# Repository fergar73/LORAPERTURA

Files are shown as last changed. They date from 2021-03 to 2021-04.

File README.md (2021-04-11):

## LORAPERTURA
El dispositivo lorapertura permite saber cuando una puerta está abierta o cerrada e informar de su estado a traves de la red Lorawan abierta y global [The Things Network](https://www.thethingsnetwork.org). Ofrece información de temperatura, presión y humedad del sitio donde esté instalado así como la luminosidad del espacio.
En la [presentación del proyecto](./presentacion/lorapertura-ttnmad.pdf) puedes consultar algunos detalles adicionales. 
- [English README file](README-EN.md)

### Hardware
Listado de componentes necesarios para la construcción del dispositivo
- Nodo TTN Madrid: Consulta esta  [documentación]( https://github.com/IoTopenTech/Nodo_TTN_MAD_V2) y sigue los pasos de esta [guía](https://github.com/IoTopenTech/Nodo_TTN_MAD_V2/blob/master/Montaje%20nodo%20TTN%20MAD%20v2_2%20basico.pdf) para construirlo.
- Sensor magnético puerta abierta
- Sensor Bosch BME280
- Sensor TEMT6000 

En la presentacion se indica la forma elegida de conectar los sensores al nodo TTN Madrid.

### Software
Se proporcionan dos programas ".ino" de arduino en el directorio del software dependiendo de la forma preferida (OTAA O ABP) de conectar el dispositivo a [The Things Network](https://www.thethingsnetwork.org).

Se ha utilizado el Arduino IDE para este proyecto, los detalles se indican en [SW-Arduino-IDE](software/SW-Arduino-IDE.md)

### 3D - Caja Dispositivo 
Se propone una caja de interior junto con su tapa para fijar el dispositivo a la pared en la carpeta caja-3d. Este dispositivo se ha realizado utilizando [freecad](https://www.freecadweb.org)
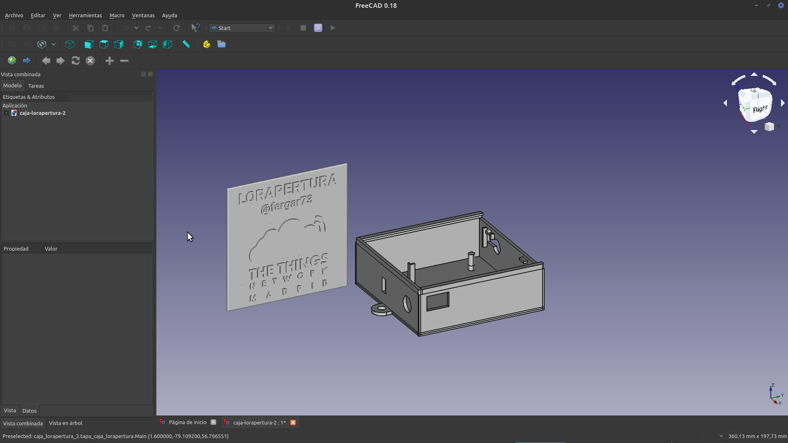
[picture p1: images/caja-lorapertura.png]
caja-lorapertura


### Visualización de Datos
La capa de presentación y control del dispositivo lorapertura se ha realizado utilizando [myiotopentech](https://my.iotopentech.io/) que está básado en la plataforma de código abierto [thingsboard](https://thingsboard.io/) que permite gestionar la recolección de datos de dispositivos de IoT, su procesamiento y visualización. 
Aquí está [la información detallada de myiotopentech]( https://github.com/IoTopenTech/myIoTopenTech). El nombre interno del dispositivo lorapetura es TTNMAD-DOOR-BME280-TEMT6000 y a continuación se muestra el panel principal que muestra los datos de lorapertura
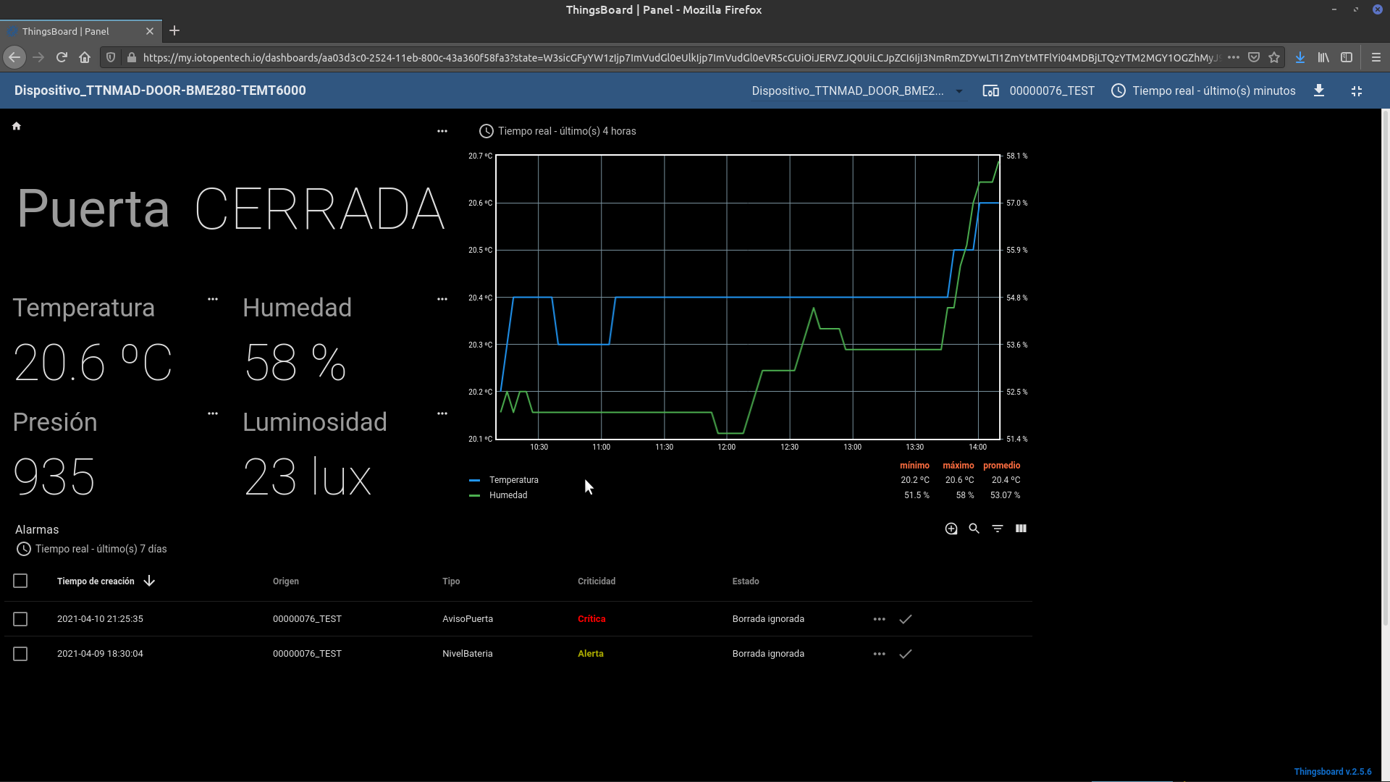
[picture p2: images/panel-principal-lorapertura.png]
panel principal


### Contribuciones
Se pueden realizar contribuciones al proyecto, puedes hacer un fork en local y plantear los pull-request con las mejoras realizadas.

### Licencia
LORAPERTURA © 2021 por fergar73 esta bajo licencia CC BY-NC-SA [Creative Commons Reconocimiento-NoComercial-CompartirIgual 4.0 Internacional License](http://creativecommons.org/licenses/by-nc-sa/4.0/)
 
### Agradecimientos
Este proyecto ha sido posible gracias a la extraordinaria labor que se está realizando la comunidad [The Things Network Madrid](https://www.thethingsnetwork.org/community/madrid/)

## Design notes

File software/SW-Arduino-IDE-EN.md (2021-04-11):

## Build on Arduino IDE
You can install the Arduino IDE by downloading it from [arduino.cc](https://www.arduino.cc). This project has been developed using 1.8.13 release. 

### Installing dependencies
This project relies on several third party dependencies that must be installed in order to be able to build the binary. Below the list of libraries used:

- <lmic.h>             // For the Lorawan comunication - Release v2.3.2
https://github.com/mcci-catena/arduino-lmic
- <LowPower.h>         // To allow the low power arduino energy  consumption Release v1.6.0
https://github.com/rocketscream/Low-Power
- <forcedClimate.h>    // Getting BME280 data Release v3.0.0
https://github.com/JVKran/Forced-BME280
- <YetAnotherPcInt.h>  // To choose the port for the door control interruption Release v2.1.0
https://github.com/paulo-raca/YetAnotherArduinoPcIntLibrary 
- <CayenneLPP.h>       // Cayenne Library for the payload format Release v1.0.1
https://github.com/ElectronicCats/CayenneLPP

Once you have installed and downloaded the repository in the software directory, the code is available to compile it and upload it to the lorapertura device.
Remember that you must fill in the specific data of your device in FILLMEIN depending on the configuration (OTAA or ABP) of your device in [The Things Network](https://www.thethingsnetwork.org) 

Code to replace FILLMEIN in ABP device
```c
// LoRaWAN NwkSKey, network session key
static const PROGMEM u1_t NWKSKEY[16] = { FILLMEIN } ;`

// LoRaWAN AppSKey, application session key
static const u1_t PROGMEM APPSKEY[16] = { FILLMEIN } ;

// LoRaWAN end-device address (DevAddr)
// See http://thethingsnetwork.org/wiki/AddressSpace
// The library converts the address to network byte order as needed.
static const u4_t DEVADDR = FILLMEIN ; // <-- Change this address for every node!
```

### Select board and upload the binary 
Two options selecting the board depending on the bootloader of the ttnmad node:
If you load the Minicore bootloader as indicated in the doc as optional then select ATmega328 board
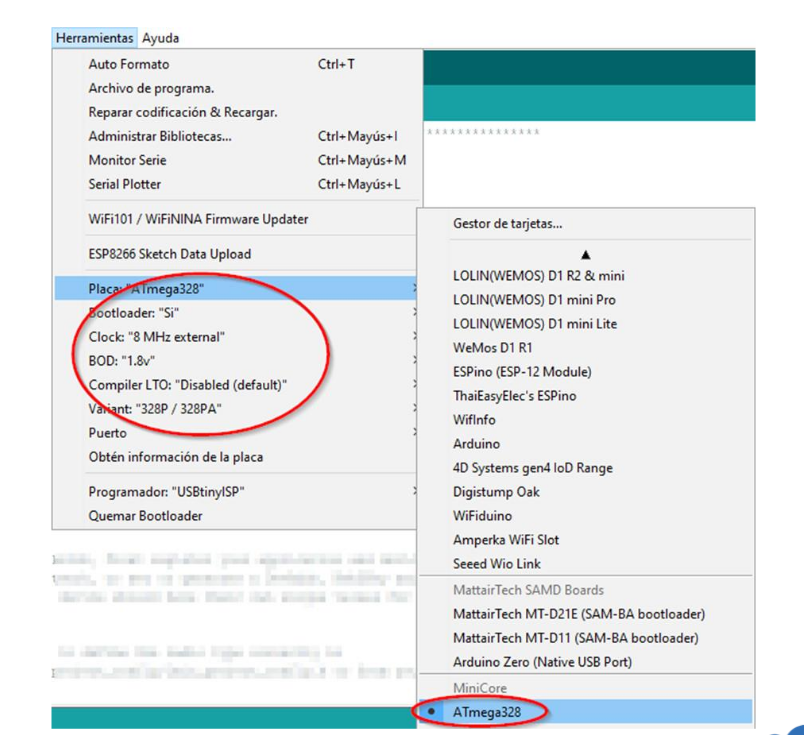
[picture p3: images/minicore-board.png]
minicore

otherwise you have to choose the "Arduino Pro or Pro Mini" board.
arduino-mini
Then select the port where the board is connected to the computer in Tools > Ports
And finally click on the rounded arrow button on the top to upload the project to the board or go to Program > Upload (Ctl+U)

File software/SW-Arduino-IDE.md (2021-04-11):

## Programación con Arduino IDE
Puedes instalar el arduino IDE disponible en [arduino.cc](https://www.arduino.cc). Este proyecto ha sido desarrollado con la versión 1.8.13.

### Dependencias
Este proyecto requiere de la instalación en el arduino IDE de las siguientes librerías. Son necesarias para la compilación y correcto funcionamiento del dispositivo. 

- <lmic.h>             // For the Lorawan comunication - Release v2.3.2
https://github.com/mcci-catena/arduino-lmic
- <LowPower.h>         // To allow the low power arduino energy  consumption Release v1.6.0
https://github.com/rocketscream/Low-Power
- <forcedClimate.h>    // Getting BME280 data Release v3.0.0
https://github.com/JVKran/Forced-BME280
- <YetAnotherPcInt.h>  // To choose the port for the door control interruption Release v2.1.0
https://github.com/paulo-raca/YetAnotherArduinoPcIntLibrary 
- <CayenneLPP.h>       // Cayenne Library for the payload format Release v1.0.1
https://github.com/ElectronicCats/CayenneLPP

Una vez tengas instalado y descargado el repositorio en el directorio software está el código disponible para compilarlo y subirlo al dispositivo lorapertura.
Recuerda que debes rellenar los datos concreto de tu dispositivo en FILLMEIN dependiendo de la configuración (OTAA o ABP) de tu dispositivo en [The Things Network](https://www.thethingsnetwork.org)

Lugar del código activación ABP donde sustituir el FILLMEIN 
```c
// LoRaWAN NwkSKey, network session key
static const PROGMEM u1_t NWKSKEY[16] = { FILLMEIN } ;`

// LoRaWAN AppSKey, application session key
static const u1_t PROGMEM APPSKEY[16] = { FILLMEIN } ;

// LoRaWAN end-device address (DevAddr)
// See http://thethingsnetwork.org/wiki/AddressSpace
// The library converts the address to network byte order as needed.
static const u4_t DEVADDR = FILLMEIN ; // <-- Change this address for every node!
```

### Selección de la placa y carga del programa en el dispositivo

Hay 2 opciones de seleccionar la placa dependiendo del "bootloader" que tenga cargado el nodo TTNMAD.
Si tiene cargado el Minicore bootloader que se indica en la documentación como paso opcional, hay que indicar la placa ATmega328 
minicore
si no es el caso hay que seleccionar la placa "Arduino Pro or Pro Mini" con procesador ATmega328P (3.3V,8MHz).
arduino-mini
Seleciona el puerto que esté conectado a la placa y mediante el arduino IDE pulsa la opción de subir el código (Ctl+U)

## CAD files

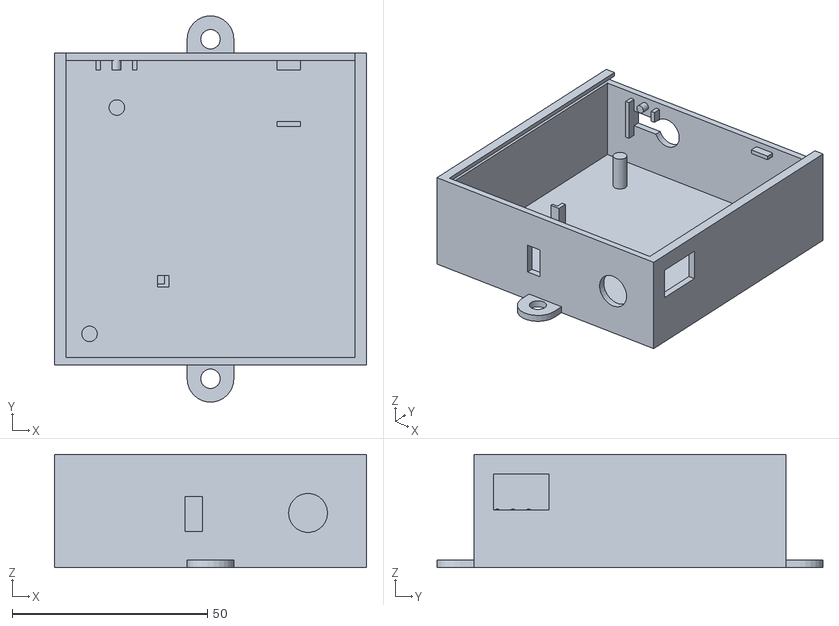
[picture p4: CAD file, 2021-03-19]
caja-3d/caja-lorapertura.stl
80.0 x 98.9 x 29.0

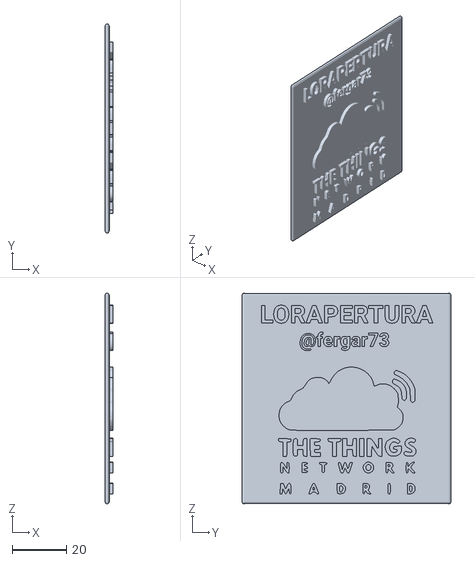
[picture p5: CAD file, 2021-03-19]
caja-3d/tapa-caja-lorapertura.stl
3.00 x 76.9 x 77.6

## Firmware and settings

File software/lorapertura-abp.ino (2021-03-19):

/*******************************************************************************
 * Copyright (c) 2015 Thomas Telkamp and Matthijs Kooijman
 * Copyright (c) 2018 Terry Moore, MCCI
 * Copyright (c) 2020 Fernando García Martín
 *
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
 *
 * This uses ABP (Activation-by-personalisation), where a DevAddr and
 * Session keys are preconfigured (unlike OTAA, where a DevEUI and
 * application key is configured, while the DevAddr and session keys are
 * assigned/generated in the over-the-air-activation procedure).
 *
 * Note: LoRaWAN per sub-band duty-cycle limitation is enforced (1% in
 * g1, 0.1% in g2), but not the TTN fair usage policy (which is probably
 * violated by this sketch when left running for longer)!
 *
 * To use this sketch, first register your application and device with
 * the things network, to set or generate a DevAddr, NwkSKey and
 * AppSKey. Each device should have their own unique values for these
 * fields.
 *
 * Do not forget to define the radio type correctly in
 * arduino-lmic/project_config/lmic_project_config.h or from your BOARDS.txt.
 *
 *******************************************************************************/

 // References:
 // [feather] adafruit-feather-m0-radio-with-lora-module.pdf

#include <lmic.h>             // Libreria para la implementación del protocolo Lorawan
#include <hal/hal.h>          // Hardware Abstraction Layer for LMIC
#include <SPI.h>              // Bus SPI - utilizado para la comunicación con el RFM95
#include <Wire.h>             // Bus I2C - utilizado para comunicación con el BME280
#include "LowPower.h"         // Librería para la gestión de bajo consumo del arduino
#include <forcedClimate.h>    // Librería para acceder al sensor BME280 con bajo consumo de memoria
#include <YetAnotherPcInt.h>  // Permite elegir el puerto para la gestión de la interrupción de puerta abierta.
#include <CayenneLPP.h>       // Construcción del payload en formato Cayenne

// Define el SpreadFactor fijo que se utilizará en la transmisión Lora
#define SpreadFactor DR_SF7
// Indicar el tiempo que tarda el mensaje en el aire según el Spread Factor indicado
// se puede utilizar para ello la utilidad: https://avbentem.github.io/airtime-calculator/ttn
const unsigned long airTimeMs = 61.7;  // Expresado en milisegundos

unsigned int frecuenciaEnvioMsg;  // Tiempo en segundos entre cada envio de mensaje, calculado en función del airTimeMs 
unsigned int tiempoDormido = 0;   // Control del tiempo que el procesador esta en modo LowPower

boolean modoAhorroEnergia = true; // Para activar o desactivar el modo LowPower  

// Definición de Pin A2 para Interrupción Sensor Puerta Abierta
#define pinEventoPuertaAbierta A2

// Variables para el control de la interrupción de Puerta Abierta 
volatile boolean eventoPuertaAbierta = false;   // Cuando se abre la puerta salta la interrupción y estará a true. Inicializada a false
boolean ev_antes_envio = false;                 // Contiene el valor de la variable eventoPuertaAbierta antes del envío.
boolean ev_despues_envio = false;               // Contiene el valor de la variable eventoPuertaAbierta despues del envío.

// Sensor de luminosidad - TEMT6000  
#define LIGHTSENSORPIN A0     //Conectado al pin Analogico A0 light sensor reading 
float lux = 0.0;              // Variable para enviar la luminosidad en lux

// Sensor BME280 conectado al puerto I2C en la dirección 0x76 para obtener datos de temperatura, presión y humedad
ForcedClimate climateSensor = ForcedClimate();

// Variable en formato Cayenne para el envío del payload a TTN. Se indica tamaño de cada campo del payload.
// LPP_ANALOG_INPUT_SIZE 4        -- 2 bytes  -- "analog_in_1"
// LPP_DIGITAL_OUTPUT_SIZE 3      -- 1 byte   -- "digital_out_2" y "digital_out_3"
// LPP_TEMPERATURE_SIZE 4         -- 2 bytes  -- "temperature_4"
// LPP_BAROMETRIC_PRESSURE_SIZE 4 -- 2 bytes  -- "barometric_pressure_5"
// LPP_RELATIVE_HUMIDITY_SIZE 3   -- 1 byte   -- "relative_humidity_6"
// LPP_LUMINOSITY_SIZE 4          -- 2 bytes  -- "luminosity_7"
CayenneLPP lpp(25);

// For normal use, we require that you edit the sketch to replace FILLMEIN
// with values assigned by the TTN console. However, for regression tests,
// we want to be able to compile these scripts. The regression tests define
// COMPILE_REGRESSION_TEST, and in that case we define FILLMEIN to a non-
// working but innocuous value.
//
#ifdef COMPILE_REGRESSION_TEST
# define FILLMEIN 0
#else
# warning "You must replace the values marked FILLMEIN with real values from the TTN control panel!"
# define FILLMEIN (#dont edit this, edit the lines that use FILLMEIN)
#endif

// LoRaWAN NwkSKey, network session key
static const PROGMEM u1_t NWKSKEY[16] = { FILLMEIN } ;

// LoRaWAN AppSKey, application session key
static const u1_t PROGMEM APPSKEY[16] = { FILLMEIN } ;

// LoRaWAN end-device address (DevAddr)
// See http://thethingsnetwork.org/wiki/AddressSpace
// The library converts the address to network byte order as needed.
static const u4_t DEVADDR = FILLMEIN ; // <-- Change this address for every node!

// These callbacks are only used in over-the-air activation, so they are
// left empty here (we cannot leave them out completely unless
// DISABLE_JOIN is set in arduino-lmic/project_config/lmic_project_config.h,
// otherwise the linker will complain).
void os_getArtEui (u1_t* buf) { }
void os_getDevEui (u1_t* buf) { }
void os_getDevKey (u1_t* buf) { }

static osjob_t sendjob;

// Pin mapping
// Adapted for Feather M0 per p.10 of [feather]
const lmic_pinmap lmic_pins = {
    .nss = 10,                       // chip select on feather (rf95module) CS
    .rxtx = LMIC_UNUSED_PIN,
    .rst = 9,                       // reset pin
    .dio = {2, 7, LMIC_UNUSED_PIN}, // assumes external jumpers [feather_lora_jumper]
                                    // DIO1 is on JP1-1: is io1 - we connect to GPO6
                                    // DIO1 is on JP5-3: is D2 - we connect to GPO5
};

int contador = 0;
boolean completado = false;

unsigned long inicio;   // Para controlar los tiempos de espera sin utilizar función delay.
unsigned long actual;   // Para controlar los tiempos de espera sin utilizar función delay.
unsigned long fin;      // Para controlar los tiempos de espera sin utilizar función delay.


// Funcion que devuelve el voltaje de las baterías
// Fuente Juan Félix Mateos - Talleres nodo v2.2 TTN MAD

long readVcc() {
  ADMUX = _BV(REFS0) | _BV(MUX3) | _BV(MUX2) |
  _BV(MUX1);
  delay(2);
  ADCSRA |= _BV(ADSC);
  while (bit_is_set(ADCSRA, ADSC));
  long result = ADCL;
  result |= ADCH << 8;
  result = 1126400L / result; // Back-calculate AVcc in mV
  return result;
}

void onEvent (ev_t ev) {
    Serial.print(os_getTime());
    Serial.print(": ");
    switch(ev) {
        case EV_SCAN_TIMEOUT:
            Serial.println(F("EV_SCAN_TIMEOUT"));
            break;
        case EV_BEACON_FOUND:
            Serial.println(F("EV_BEACON_FOUND"));
            break;
        case EV_BEACON_MISSED:
            Serial.println(F("EV_BEACON_MISSED"));
            break;
        case EV_BEACON_TRACKED:
            Serial.println(F("EV_BEACON_TRACKED"));
            break;
        case EV_JOINING:
            Serial.println(F("EV_JOINING"));
            break;
        case EV_JOINED:
            Serial.println(F("EV_JOINED"));
            break;
        /*
        || This event is defined but not used in the code. No
        || point in wasting codespace on it.
        ||
        || case EV_RFU1:
        ||     Serial.println(F("EV_RFU1"));
        ||     break;
        */
        case EV_JOIN_FAILED:
            Serial.println(F("EV_JOIN_FAILED"));
            break;
        case EV_REJOIN_FAILED:
            Serial.println(F("EV_REJOIN_FAILED"));
            break;
        case EV_TXCOMPLETE:
            if (LMIC.txrxFlags & TXRX_ACK)
              Serial.println(F("Received ack"));
            if (LMIC.dataLen) {
              Serial.println(F("Received "));
              Serial.println(LMIC.dataLen);
              Serial.println(F(" bytes of payload"));
            }
            // Variable completado se marca a cierto cuando se ha completado la transacción de envío.
            // Nos sirve para dar paso al próximo ciclo de envío con la seguridad que la transacción que estaba siendo gestionada ha terminado.
            completado = true;  
            Serial.println(F("EV_TXCOMPLETE (includes waiting for RX windows)"));
            break;
        case EV_LOST_TSYNC:
            Serial.println(F("EV_LOST_TSYNC"));
            break;
        case EV_RESET:
            Serial.println(F("EV_RESET"));
            break;
        case EV_RXCOMPLETE:
            // data received in ping slot
            Serial.println(F("EV_RXCOMPLETE"));
            break;
        case EV_LINK_DEAD:
            Serial.println(F("EV_LINK_DEAD"));
            break;
        case EV_LINK_ALIVE:
            Serial.println(F("EV_LINK_ALIVE"));
            break;
        /*
        || This event is defined but not used in the code. No
        || point in wasting codespace on it.
        ||
        || case EV_SCAN_FOUND:
        ||    Serial.println(F("EV_SCAN_FOUND"));
        ||    break;
        */
        case EV_TXSTART:
            Serial.println(F("EV_TXSTART"));
            break;
        default:
            Serial.print(F("Unknown event: "));
            Serial.println((unsigned) ev);
            break;
    }
}

void do_send(osjob_t* j){

    // Check if there is not a current TX/RX job running
    if (LMIC.opmode & OP_TXRXPEND) {
        Serial.println(F("OP_TXRXPEND, not sending"));
    } else {
    // Prepare upstream data transmission at the next possible time.
        lpp.reset();
        lpp.addAnalogInput(1, readVcc() / 1000.F);                        // Enviamos Voltaje actual 
        climateSensor.takeForcedMeasurement();                            // Obtenemos los datos de temperatura, presión y humedad del BME280
        lpp.addTemperature(4, climateSensor.getTemperatureCelcius());     // Enviamos la medición de temperatura
        lpp.addBarometricPressure(5, climateSensor.getPressure());        // Enviamos la medición de presión
        lpp.addRelativeHumidity(6, climateSensor.getRelativeHumidity());  // Enviamos la medición de humedad
        lux = ((((analogRead(LIGHTSENSORPIN) * 3.3 / 1024) / 10000.0) * 1000000) * 2.0 );  // Obtenemos la medición de luminosidad de TEMT6000 y la pasamos a lux
        lpp.addLuminosity(7,lux);                                         // Enviamos la medición de luminosidad        
        ev_antes_envio = eventoPuertaAbierta;                             // Guardamos el valor del eventoPuertaAbierta antes del envío
        lpp.addDigitalOutput(2, eventoPuertaAbierta);                     // Enviamos valor de eventoPuertaAbierta para saber si ha saltado la interrupción de Puerta Abierta
        lpp.addDigitalOutput(3, digitalRead(pinEventoPuertaAbierta));     // Estado de la puerta 1 => Cerrada || 0 => Abierta
        LMIC.pendTxConf = eventoPuertaAbierta;                            // Si se ha producido el evento de puerta abierta activamos el envío del mensaje con ACK
        LMIC_setTxData2(1, lpp.getBuffer(), lpp.getSize(), LMIC.pendTxConf);  //  Se hace el envío del mensaje a TTN
        ev_despues_envio = eventoPuertaAbierta;                           // Guardamos el valor del eventoPuertaAbierta despues del envío
        Serial.print(F("Paquete enviado a TTN "));
        Serial.print("ev_antes_envio ");Serial.print(ev_antes_envio);
        Serial.print(" ev_despues_envio ");Serial.print(ev_despues_envio);
        Serial.print(" eventoPuertaAbierta ");Serial.println(eventoPuertaAbierta);
        if (ev_antes_envio && ev_despues_envio && eventoPuertaAbierta) {
          eventoPuertaAbierta = false;            // Se ha confirmado el envio a TTN con ACK del eventoPuertaAbierta. Se inicializa a falso para el siguiente ciclo de envío.
          Serial.print("EventoPuertaReseteado ");Serial.println(eventoPuertaAbierta);
        }  
    }
    // Next TX is scheduled after TX_COMPLETE event.
}

// Función de la Interrupción de Puerta Abierta.
void abriendoPuerta()
{
  eventoPuertaAbierta = true;        // Al saltar la interrupción de Puerta Abierta, se establece a cierto/true la variable eventoPuertaAbierta
  Serial.println(F("Evento puerta"));
}

// Funcion similar al delay pero que tiene en cuenta la interrupción de puerta abierta para gestionarla sin esperas.
// Si eventoPuertaAbierta es true, la función no quedará en espera.
void esperaConInterrupciones(unsigned long milisegundosEspera)
{
    actual = millis();
    fin = actual + milisegundosEspera;
    while ( (actual <= fin) & (not eventoPuertaAbierta)) {
      actual = millis();
    }
}

void setup() {
    // Encendemos pin para marcar inicio del setup
    pinMode(13,OUTPUT);
    digitalWrite(13,HIGH);

    // Depuración y traza de la programación a traves del puerto Serie a 115200 baudios
    while (!Serial); // wait for Serial to be initialized
    Serial.begin(115200);

    // Revisar la utilidad de este delay
    esperaConInterrupciones(50);    
    Serial.println(F("Setup-Inicio Lorapertura"));
    
    // Asociamos el pinEventoPuertaAbierta a la Interrupción.
    pinMode(pinEventoPuertaAbierta, INPUT_PULLUP);
    PcInt::attachInterrupt(pinEventoPuertaAbierta, abriendoPuerta, FALLING);
    Serial.print(F("Interrupcion preparada.."));

    // Asociamos el pin de entrada analogico al sensor TEMT6000
    pinMode(LIGHTSENSORPIN,  INPUT);  
    Serial.print(F("Sensor Lux asociado.."));
    
    // Arrancamos comunicación con el sensor BME280    
    climateSensor.begin();  
    Serial.print(F("Sensor BME280 listo.."));
    
// Esperamos un medio segundo antes de iniciarlizar la comunicación Lora
    esperaConInterrupciones(500);

    // LMIC init
    os_init();
    // Reset the MAC state. Session and pending data transfers will be discarded.
    LMIC_reset();

    // Set static session parameters. Instead of dynamically establishing a session
    // by joining the network, precomputed session parameters are be provided.
    #ifdef PROGMEM
    // On AVR, these values are stored in flash and only copied to RAM
    // once. Copy them to a temporary buffer here, LMIC_setSession will
    // copy them into a buffer of its own again.
    uint8_t appskey[sizeof(APPSKEY)];
    uint8_t nwkskey[sizeof(NWKSKEY)];
    memcpy_P(appskey, APPSKEY, sizeof(APPSKEY));
    memcpy_P(nwkskey, NWKSKEY, sizeof(NWKSKEY));
    LMIC_setSession (0x13, DEVADDR, nwkskey, appskey);
    #else
    // If not running an AVR with PROGMEM, just use the arrays directly
    LMIC_setSession (0x13, DEVADDR, NWKSKEY, APPSKEY);
    #endif

    #if defined(CFG_eu868)
    // Set up the channels used by the Things Network, which corresponds
    // to the defaults of most gateways. Without this, only three base
    // channels from the LoRaWAN specification are used, which certainly
    // works, so it is good for debugging, but can overload those
    // frequencies, so be sure to configure the full frequency range of
    // your network here (unless your network autoconfigures them).
    // Setting up channels should happen after LMIC_setSession, as that
    // configures the minimal channel set.
    LMIC_setupChannel(0, 868100000, DR_RANGE_MAP(DR_SF12, DR_SF7),  BAND_CENTI);      // g-band
    LMIC_setupChannel(1, 868300000, DR_RANGE_MAP(DR_SF12, DR_SF7B), BAND_CENTI);      // g-band
    LMIC_setupChannel(2, 868500000, DR_RANGE_MAP(DR_SF12, DR_SF7),  BAND_CENTI);      // g-band
    LMIC_setupChannel(3, 867100000, DR_RANGE_MAP(DR_SF12, DR_SF7),  BAND_CENTI);      // g-band
    LMIC_setupChannel(4, 867300000, DR_RANGE_MAP(DR_SF12, DR_SF7),  BAND_CENTI);      // g-band
    LMIC_setupChannel(5, 867500000, DR_RANGE_MAP(DR_SF12, DR_SF7),  BAND_CENTI);      // g-band
    LMIC_setupChannel(6, 867700000, DR_RANGE_MAP(DR_SF12, DR_SF7),  BAND_CENTI);      // g-band
    LMIC_setupChannel(7, 867900000, DR_RANGE_MAP(DR_SF12, DR_SF7),  BAND_CENTI);      // g-band
    LMIC_setupChannel(8, 868800000, DR_RANGE_MAP(DR_FSK,  DR_FSK),  BAND_MILLI);      // g2-band
    // TTN defines an additional channel at 869.525Mhz using SF9 for class B
    // devices' ping slots. LMIC does not have an easy way to define set this
    // frequency and support for class B is spotty and untested, so this
    // frequency is not configured here.
    #elif defined(CFG_us915)
    // NA-US channels 0-71 are configured automatically
    // but only one group of 8 should (a subband) should be active
    // TTN recommends the second sub band, 1 in a zero based count.
    // https://github.com/TheThingsNetwork/gateway-conf/blob/master/US-global_conf.json
    LMIC_selectSubBand(1);
    #endif

    // 
    LMIC_setAdrMode(0);
    // Disable link check validation
    LMIC_setLinkCheckMode(0);

    // TTN uses SF9 for its RX2 window.
    LMIC.dn2Dr = DR_SF9;

    // Set data rate and transmit power for uplink (note: txpow seems to be ignored by the library)
    LMIC_setDrTxpow(SpreadFactor,14);

    // Se amplia la ventana para la recepción del downlink del ack de los mensajes certificados.
    LMIC_setClockError(MAX_CLOCK_ERROR * 10 / 100);

    Serial.println(F("LMIC Lorawan Ready"));

    // Se calcula la frecuencia de envio de mensajes de acuerdo a la politica de acceso justo establecida en The Things Network
    frecuenciaEnvioMsg = 86400 / (30000 / airTimeMs);
    Serial.println(frecuenciaEnvioMsg);

    // Se avisa con parpadeo del led del fin del setup
    for (int led=0; led <= 3; led++){
          digitalWrite(13,HIGH);
          esperaConInterrupciones(500);
          digitalWrite(13,LOW);
          esperaConInterrupciones(500);
   } 
    Serial.println(F("Setup-Fin Lorapertura"));
}

void loop() {
  tiempoDormido = 0;
  Serial.print(contador);Serial.println(F(" Empezamos ciclo loop"));
  if (modoAhorroEnergia) {
    Serial.println(F(" Modo dormido"));
    do {
      LowPower.powerDown(SLEEP_8S, ADC_OFF, BOD_OFF);       // Modo arduino dormido por 8 segundos  -- SLEEP_8S
      tiempoDormido = tiempoDormido + 8;    
    } while ((tiempoDormido < frecuenciaEnvioMsg) & (not eventoPuertaAbierta));   // En caso de puerta abierta se avanza para el envio del mensaje
  }
  else {
    Serial.println(F(" Modo espera"));
    esperaConInterrupciones(long(frecuenciaEnvioMsg) * 1000);
  }
  Serial.print(contador);Serial.println(F(" Send to TTN"));
  do_send(&sendjob);      // Toma de medidas y envío del mensaje a TTN en el próximo ciclo
  Serial.print(contador);Serial.println(F(" While not completado"));
  do {
    os_runloop_once();    // Gestión del envío y recepción de mensajes enviados por la librería LMIC. Variable completado indica que podemos avanzar al siguiente ciclo de envío.      
  } while (not completado);
  completado = false;           // Actualizar completado a falso para el próximo ciclo de envío
  ev_antes_envio = false;       // Se inicializa el control de envío de puerta abierta antes.
  ev_despues_envio = false;     // Se inicializa el control de envío de puerta abierta despues.
  // En algun caso para asegurar la recepción de mensajes certificados se hacen reintentos automáticos incrementando el  SF 
  // Se sobreescribe el SpreadFactor para asegurar el envío en el SF definido.
  LMIC_setDrTxpow(SpreadFactor,14);    
  Serial.print(contador);Serial.println(F(" Terminamos ciclo loop"));
  contador = contador + 1;      
}        

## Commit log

2020-03-29 Interrupción Básica Puerta Abierta
    Primera versión con interrupción básica puerta abierta con SF 8.
    Faltaría mejorar la gestión de las variables para control del evento de puerta abierta.
2020-04-12 Interrupcion + BME280 + TEMT6000 (no lux)
    Versión "estable" de envío con control de interrupción apertura puerta + BME280 + TEMT6000 no lux. El envío se hace con SF9. El evento de apertura de puerta tiene la lógica de envío con ACK.
2020-11-09 Utilización Forced BME280
    Con utilización de la librería forced BME280 y delay 3 minutos
2020-11-29 Revisión Interrupciones - 29-11-2020
    Incluye las modificaciones realizadas en la revisión de interrupciones y ajuste de Spread Factor al final del loop
2021-01-30 Version 0.1 casi definitiva
    Incluye gestión de frecuencia de envío y cálculo de lux
2021-03-19 Incorpora caja 3d
    [caja-lorapertura.stl, tapa-caja-lorapertura.stl]
